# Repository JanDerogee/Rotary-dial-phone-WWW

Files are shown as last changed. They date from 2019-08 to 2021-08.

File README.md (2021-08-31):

# Rotary-dial-phone-WWW
Rotary dial phone WWW (for your Windows computer).

Allow your first 8 bookmarks to be opened with a number form a rotary dial phone.
Dial IP-address, using a rotary dial phone. Dial number based URL's (interesting if you like Chinese websites).
Do some basic calculations using a rotary dial phone.

Basically the phone is connected to an arduino circuit that converts the hook and dial functions into keystrokes. The magic is performed by cleverly executing sequences of standard keyboard shortcuts. Therefore no additional software needs to be installed.

For more information, visit the project page:
https://janderogee.com/projects/rotary_dial_phone_www/rotary_dial_phone_www.html

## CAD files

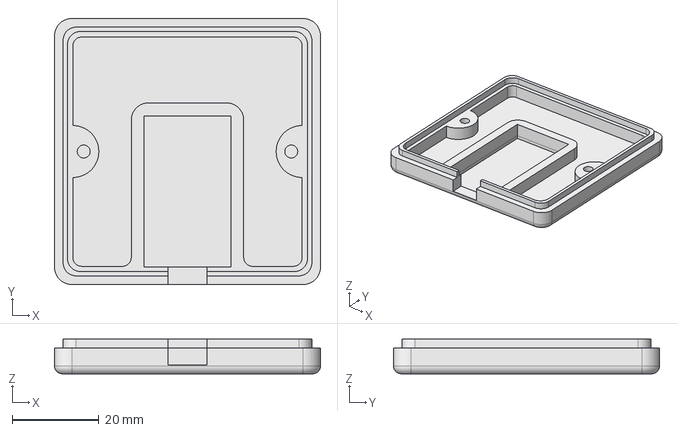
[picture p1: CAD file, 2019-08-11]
3D_printed_case_bottom/case_v1.0.FCStd
61.5 x 61.5 x 8.00 mm

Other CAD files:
3D_printed_case_bottom/case_v1.0.stl

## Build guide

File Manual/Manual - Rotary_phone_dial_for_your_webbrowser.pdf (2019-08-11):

# Rotary dial phone for your webbrowser

(for your MS Windows 7/8/10 computer in combination with Firefox)

this manual is intended for firmware version: V20190623 or higher

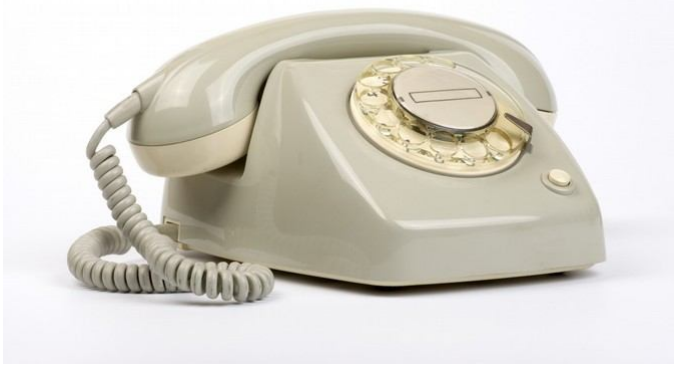
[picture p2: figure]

## By: Jan Derogee (2019)

## Introduction

Control your MS Windows 7/8/10 computer's webbrowser or calculator with an ordinary rotary dial phone. Surprise your friends or colleagues with this neat new application for obsolete tech.

Imagine this: You speak with a colleague about a specific website (that you have already bookmarked) and have a discussion about it that requires you both to take a look at it. So you offer to open a webbrowser to take a look, then you do not touch the keyboard or mouse, but reach for the rotary dial phone that was hidden underneath a pile of paperwork. You clear it out, pick up the dial, hear the dialtone and dial a number, bweeeeieieirieirieireip noises come from the receiver and the website shows up on your screen. You act like this is completely normal and continue the discussion about the contents of the site. Then when you are done, you hang up the phone and the webbrowser is closed and you continue like nothing special happened. Leaving your colleague in complete confusion about what he/she just witnessed. Now how fun is that?

You might wonder why somebody would make such a project. Well… just because for the fun of it and to maintain the skills of programming… okay… mostly for the fun of it.

2019-07-20 | Page 2 of 18 | Rotary dial phone WWW and Calc.

## Table of Contents

2019-07-20 | Page 3 of 18 | Rotary dial phone WWW and Calc.

## 1 History

### 1.1 What is a rotary phone

Rotary dial phones are the earliest user controlled phones to be mass produced. Prior to the rotary phone a user would pick up the phone, wait for the operator to answer and then tell the operator who they wanted to be connected with. With the rotary dial (pulse dialing), the user was able to make the connection themselves and therefore was no longer dependent on the speed/skill and presence of the previously used operator. This allowed the user to dial freely and at any time of day, allowing for quicker and more convenient connection to the people they wanted to speak with. This wonder of progress began to exist in 1919 and was to be slowly replaced by push buttons (tone dialing) since 1963.

### 1.2 How to use a rotary dial phone

The rotary dial phone isn't difficult to use, however it may be confusing for some people who never encountered this dialing system. Below is a wonderful set of images from WikiHow that shows you how to use this system.

First pick up the handpiece/receiver, and hold it against your ear, the cord is on the microphone side, which you should hold near your mouth while speaking. The if the first number of the telephone number you want to call is 5, place your finger in the hole with the number 5 and turn the disc, using your finger clockwise towards the fingerstop.

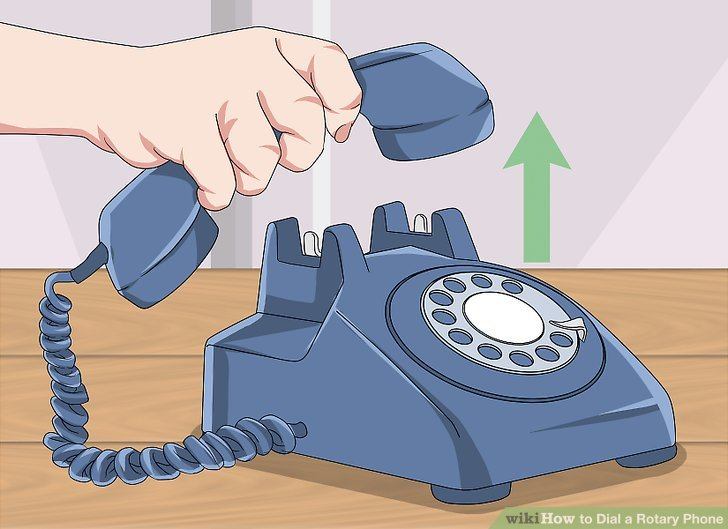
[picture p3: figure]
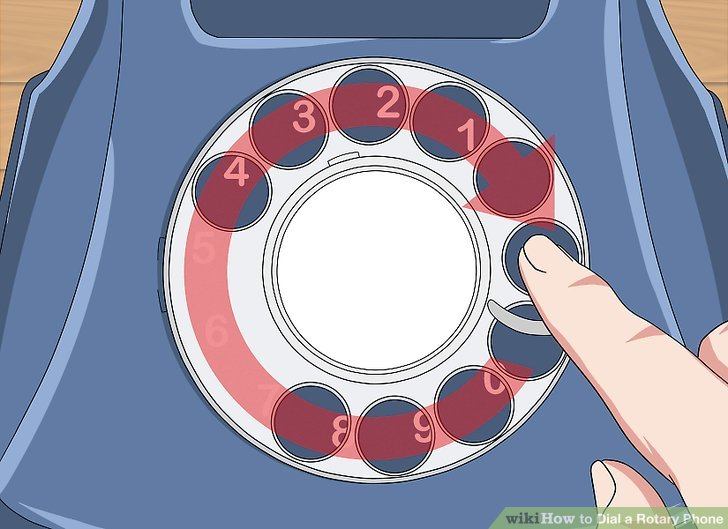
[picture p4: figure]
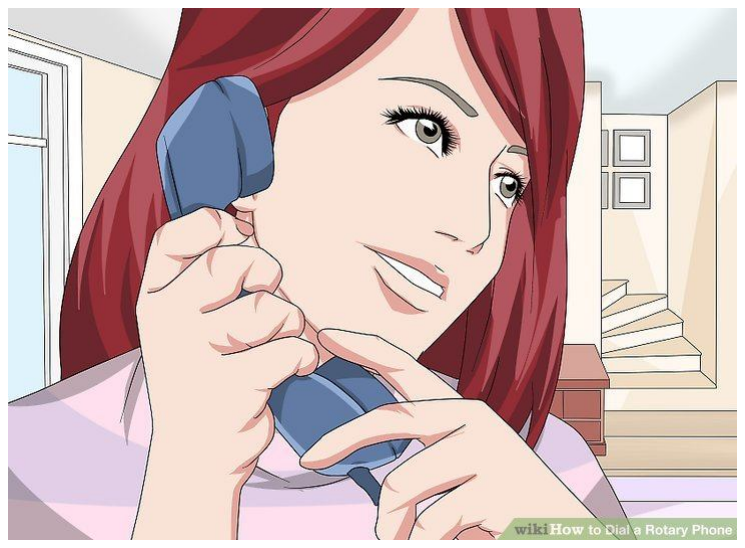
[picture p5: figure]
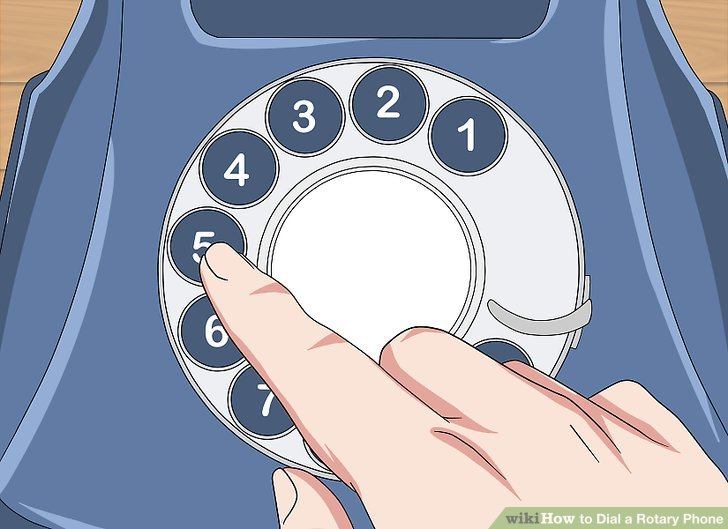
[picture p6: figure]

When your finger hits the fingerstop, pullback your finger from the disc, which will now turn back to it's original position making a soft clicking sound. When the disc stops turning dial the other numbers in the same way. When all numbers are dialed the connection is made and you may styart your conversation. Hang up the handpiece/receiver on the “hook” when your are finished.

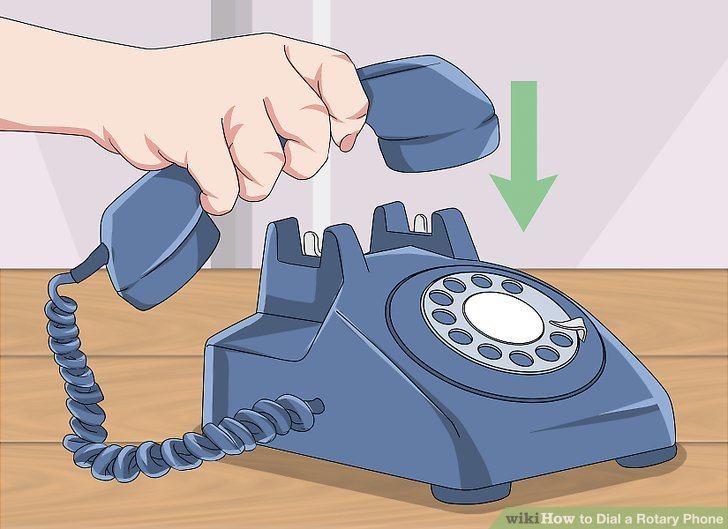
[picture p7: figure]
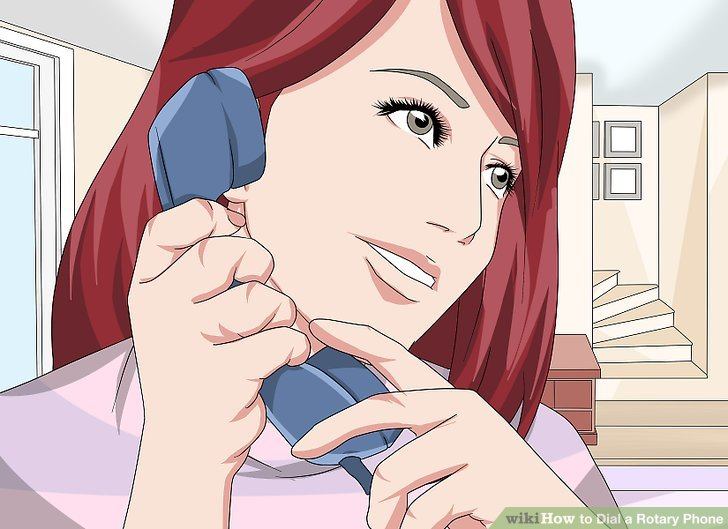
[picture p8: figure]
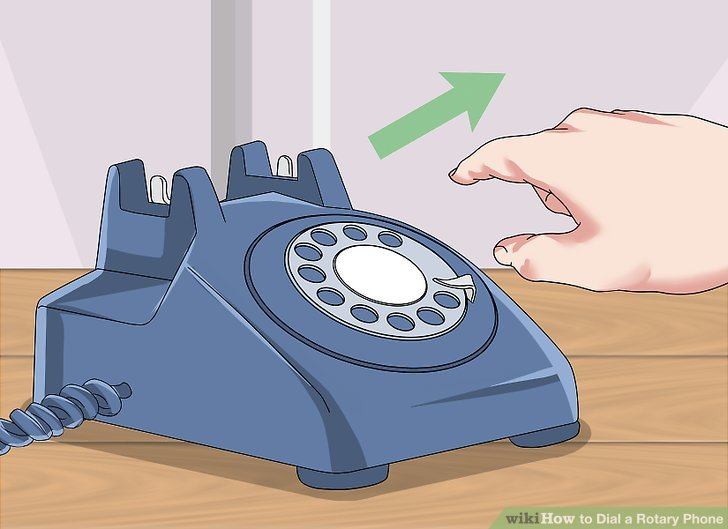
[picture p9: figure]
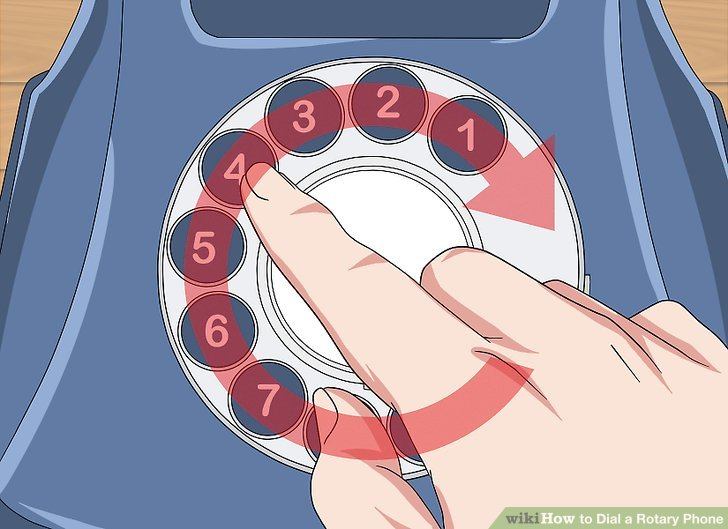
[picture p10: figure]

2019-07-20 | Page 4 of 18 | Rotary dial phone WWW and Calc.

## 2 System setup

No software needs to be installed, no special drivers are required. This device acts like a regular USB keyboard and is designed to operate with the Firefox webbrowser and the standard calculator app. But you do need to do some very simple “configurations” to your systems taskbar in order for this device to work properly:

In order to use the Firefox webbrowser it's icon should be placed onto the windows taskbar as the first item from the left. This allows it to be started using Windows+1 keyboard shortcut. You can achieve this by right clicking on the icon and selecting the option “add to taskbar” from the menu.

In order to use the calculator app it should be placed onto the windows taskbar as the second item from the left. This allows it to be started using the Windows+2 keyboard shortcut. You can achieve this by right clicking on the icon and selecting the option “add to taskbar” from the menu.

Below is an image that shows you how your taskbar could look like when this is done

## 3 Modes of operation

Now what this rotary phone to USB device does is using the phone not as a phone but as a device to control your webbrowser or calculator, by generating the keyboard codes that correspond to the functions coupled to the dial positions of the phones rotary dial.

There are 3 modes of operation, these modes of operation are described in the section “how to use” of this manual.

speeddial mode

open a webbrowser and use max. 8 different bookmarks from the bookmark menu

calculator mode

do some basic calculations usin the calculator application

IP-address and number based URL dialing mode

Dial an IP address for instance 123.1.2.3 or dial a number based URL like 126.com

2019-07-20 | Page 5 of 18 | Rotary dial phone WWW and Calc.

## 4 How to use it

The phone has a hook, a dial and a white button on the front panel. When taking the hook of the phone you can directly speed-dial a bookmark, or start the calculator app or start a browser and dial the IP address or number based URL. Pickup the handpiece/receiver, you will hear a dialtone, dial
0..9 to use a specific function: | 1..8 | = speeddial mode
| 9 | = calculator mode
| 0 | = IP / URL dial mode

The button is intended to put the dial into shifted mode.

### 4.1 Dial functions overview

The dial normally allows the user to enter a number from 0..9. However this is not enough for dialing IP-adresses or URL's. So in order to allow the user to enter different things than number alone, the small white button on the bottom-right corner of the phone is to be used to select different dial functions.

Pressing this button once activates the “shift”
function. Then dial the desired “shifted” function on
the dial. There is no way to un-shift, so if you didn't
really want a shift function and pressed the button by accident, just dial something and then delete it (by pressing the with button once followed by dialing a 1). Below an overview of the functions of the dial in normal and shifted mode.
NORMAL | SHIFTED
2019-07-20 | Page 6 of 18 | Rotary dial phone WWW and Calc.

Note: some people may ask “Why not use the character functions on the phone?”

That is a completely sensible question, because some phones have next to the numbers alphabetical characters. These characters were intended to make it easier for people to remember a phone number. As the numbers could be substituted by letters. For example: the number 0800-347396757 might be to difficult, especially when mentioned in a 10 second commercial. Therefore the number 0800-FIREWORKS would be much easier.

However, if these characters next to the
dial would be used to represent
characters from a URL, it would be
slightly | different, | as | the | device
(converting the pulses into numbers) no needs to now exactly what the user meant. When the user dialed a 5, he/she could have meant 5, J, K or L. Which is rather difficult to determine. So perhaps a scheme could be setup to dial a 5 one time for a 5, dial it 2 times for a J, 3 times for an K and 4 times for a L. Not impossible but it becomes confusing when the user want s to dial a 5 followed by a J, then you have 3 times a 5, which may be accepted as the input for a K, which is wrong. So perhaps a longer pause could be required between the numbers, but that would instantly conflict with user who want to dial quickly OR with user who dial too
slowly. Anyway, you can see where this
is going. And honestly, how many times

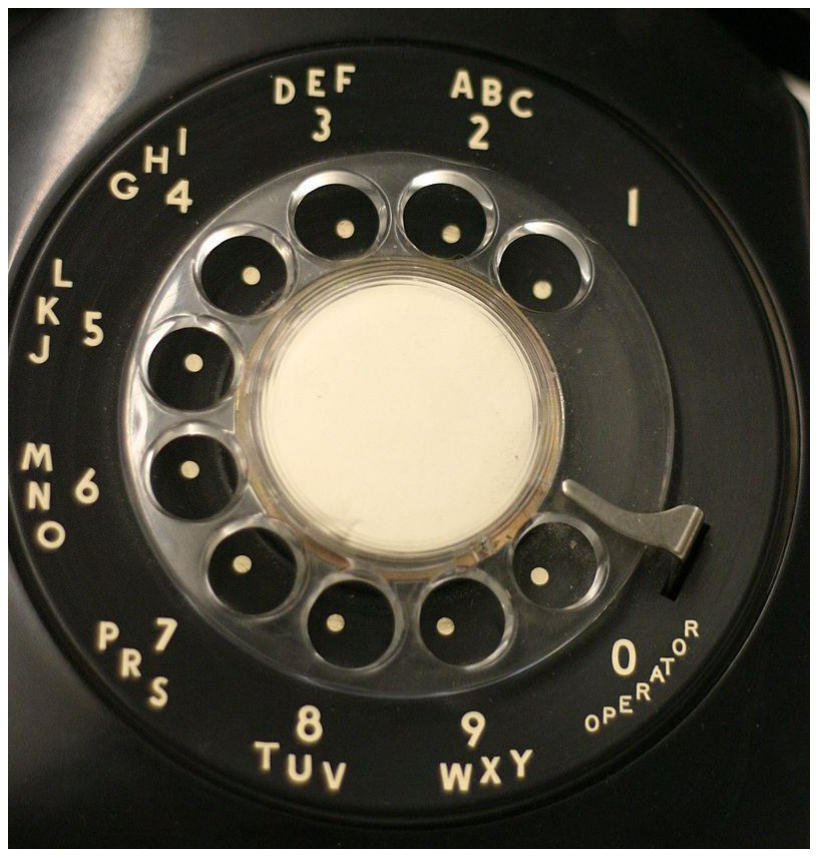
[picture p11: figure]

would you be using it, as it complicates things even further. Also the characters shown are not the complete alphabet and do not have special symbols like the '.' or the '/'. Certainly, technically everything is possible, but there is a limit to what is practically acceptable.

This project is intended as a gadget, a gag, a joke but certainly not as a full featured or serious input device. Simply because dialing y itself is rather slow and not the preferred method of choice for transferring text strings. The function of the speed dialing is perhaps the only function that makes this device slightly useable, but that's about it. Therefore during the development of this device no efforts were made to accommodate the input of raw alphabetical characters.

2019-07-20 | Page 7 of 18 | Rotary dial phone WWW and Calc.

### 4.2 Speeddial mode

The speeddial mode, will open a webbrowser and goes to the x-th item on your list of bookmarks. So assume you have a list of 25 bookmarks, then you can only access the top 8 using the speeddial function.

Pick up the handpiece/receiver, dial a number 1..8, this opens a webbrowser followed by opening the list of bookmarks. Then the cursor goes down to the selected item (1..8) and opens it.

When you are finished with the webbrowser, you must place the handpiece/reciever back onto the “hook” of the phone and the webbrowser will be closed.

In order for this to work you must setup your list of bookmarks correctly. Press CTRL+SHIFT+B to bring up the bookmarks window. The screenshot below shows how it may look like. By default it brings you to the “other bookmarks” folder and from that list it will select one of the top 8 (speeddial 1..8). If for any reason Firefox brings you to a different folder, then THAT will be the folder you must use. Although that may seems unlikely now, the other bookmarks folder wasn't default some time ago, so there is no knowing what future updates may bring us.

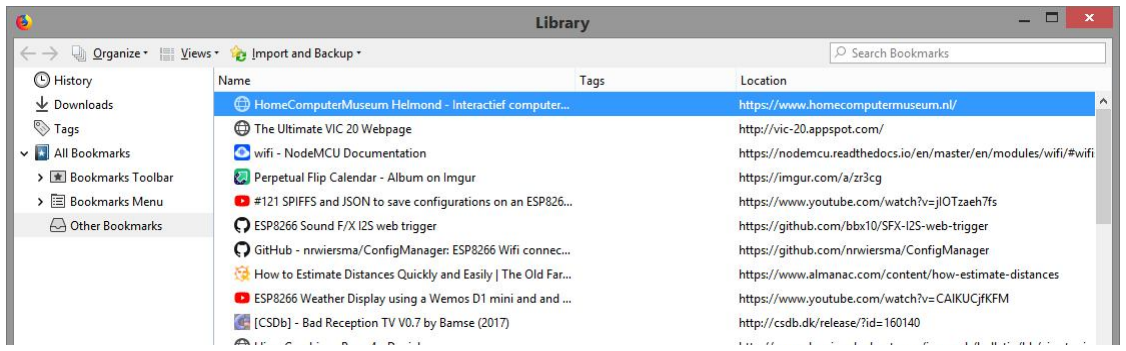
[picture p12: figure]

The top line (highlighted with blue) is the bookmark that will be started when speeddial 1 is used, the second line is the one started when speeddial 2 is used, etc. Just drag and drop the bookmarks you want to be under the speeddial in the first 8 locations of this list and that's all you need to do.

2019-07-20 | Page 8 of 18 | Rotary dial phone WWW and Calc.

### 4.3 Calculator mode

The calculator mode allows you to do some simple calculations, like adding, subtracting, multiplying and division.

Pick up the handpiece/receiver, dial a 9 to enter the calculator mode. And the calculator app will be openened. Now you can do some basic calculations by dialing the numbers 0..9 and functions . - + * / =

When you are finished with the calculator, you must place the handpiece/reciever back onto the “hook” of the phone and the calculator app will be closed.

2019-07-20 | Page 9 of 18 | Rotary dial phone WWW and Calc.

### 4.4 IP-address and number based URL dialing mode

This mode allows you to dial an IP address (i.e. 123.1.2.3) or a number based URL (i.e. 126.com).

### 4.4.1 Dial IP addresses

Pick up the handpiece/receiver, dial a 0 (just like you would dial a 0 on a company phone to connect to an outside line) and a browser will be opened.

Now you can dial the numbers of the IP address and for the '.' the 'enter' or the “.com” or any other kind of non numerical character you must use press the shift button then dial the desired character.

Unfortunately, not many websites allow you to directly visit them with an IP-address. Sometimes a warning is shown, something nothing happens at all. That's why the dialing of number based URLs is much more practical/fun.

### 4.4.2 Dial number based URL's

The Chinese, for various reasons, do use number based URL's. From a western perspective (considering I, the author of this manual, am from Europe) this sound a bit strange at first but there is a perfectly fine explanation for it, in the next chapter is explained why. But first this is how it works in practice:

Pick up handpiece/receiver, dial a 0 (just like you would dial a 0 on a company phone to connect to an outside line) and a browser will be opened.

Now you can dial the numbers of the IP address and for the '.' the 'enter' or the “.com” or any other kind of non numerical character you must use press the shift button then dial the desired character.

2019-07-20 | Page 10 of 18 | Rotary dial phone WWW and Calc.

## 5 Number based URL's and Chinese websites

Number based URL's aren't entirely non-existing but they are an exception in the western world. A few examples of the well known ones for some:

In the Netherlands, the URL 9292.nl originates from 0900-9292 (a phone number you can call to get public transport travel directions.

In Sweden there's 1177.se a website for health care

In the UK there's 111.nhs.uk an online (non urgent) emergency service. But also 118118.com which is a directory service provider that picked up a lot of popularity before mobile phones became the primary way to search for local businesses. They are still around though, and operate a website that is like a simplistic Yellow Pages / Yelp.

In Australia there's 131500.com.au the URL originates from the public transportation directions phone number of the past.

In Italy there's 187.it for Telecom Italia. Telephone companies customer service had (and still have) short numbers beginning with 1.

But the above number based URL's are merely to be considered as exceptions, we may state that most western websites have a text based URL. And having an URL or website that consists of a number may therefore be associated (by westerners) as cheap or may let them think that it really means that the most desirable version of a specific URL was already taken.

In China, though, that’s usually not the case. In fact it is the complete opposite to what most western people are accustomed to. Because if you are seriously looking at Chinese companies online, you may notice that it’s quite common for Chinese website names to include digits or even consist of numbers entirely. This is much less common with the names of English-language websites. There are a couple of reasons for this. Firstly, numbers are often easier for Chinese people to remember than Latin letters as these are not their native used symbols. Secondly, numbers often have extra meanings in Chinese. So you may now consider the fact that dialing a URL mainly consisting of numbers, using an old rotary dial phone like this project does, now becomes much less “strange” or ackward. You may even tend to believe that it could be practical to visit website using a rotary dial phone, but that would merely be a matter of personal taste.

### 5.1 Number based URL's are easy to remember

The numerals 0123456789 are used in China much as they are elsewhere in the world, and people learn them from a young age. This means they are very familiar to Chinese people and not seen as something foreign. But Latin letters, on the other hand, are generally much less familiar to many Chinese people. This may be less true for younger generations who study the Latin alphabet (thanks to Pinyin) from an early age, but in general Chinese people have less reason to use Latin letters day-to-day than they do with Arabic numerals.

The upshot of this is that Chinese website domains consisting of numbers can be much easier for Chinese people to remember than domains consisting of only Latin letters. This is often true even for domain names in pinyin – many Chinese people are not familiar with pinyin.

2019-07-20 | Page 11 of 18 | Rotary dial phone WWW and Calc.

### 5.2 Numbers have meanings in Chinese

The second reason number domain names are popular in China has to do with the huge number of homophones in the Chinese language. That is, the large amount of words that sound alike. Because there’s quite a limited amount of syllables in Chinese languages, many words end up sounding similar or identical. Numbers are no exception.

Because all numbers in Chinese sound similar to other words, it’s difficult to avoid certain associations growing between numbers and the words they sound like. This can also be put to use by intentionally choosing numbers to mimic the sounds of other words.

Here are some common associations between numbers and similar-sounding words in Chinese:
1 (一) can sound similar to ‘want’ or ‘is going to’ (要).

2 (二) can sound similar to ‘love’ (爱), but also means ‘stupid’!

3 (三) can sound similar to ‘life’ or ‘birth’ (生).

4 (四) is generally bad as it sounds like ‘death’ (死).

5 (五) is quite versatile, as it can sound similar to many different words. Most commonly it is used as ‘I / me’ (我 and 吾), and ‘not have’ (无).

6 (六) can sound like ‘flow / stream’ (流), ‘stay’ (留) and ‘fortune’ (禄).

7 (七) can sound like ‘arise’ (起).

8 (八) can sound like ‘prosper’ (发 in 发财), and two eights side-by-side (88) can look like the character for ‘double happiness’ (囍).

9 (九) can sound like ‘long lasting’ or ‘eternal’ (久).

Because of this, certain combinations of numbers can be quite significant. 14, for example, can sound like ‘will die’, and is thus quite undesirable. Similarly, 18 can sound like ‘will prosper’ and is quite desirable.

Digits are even more convenient when you consider that the words for numbers are homophones for other words. The URL for the massive e-commerce site Alibaba, for example, is 1688.com, which sounds when pronounced something like “yow-leeyoh-ba-ba”, not perfect perhaps, but very understandable and a good reminder.

But is isn't always about the way it sounds and the digits in a domain name usually aren’t random either. For example the Internet company NetEase uses the web address 163.com. This is a throwback to the days of dial-up internet when Chinese Internet users had to enter 163 to get online. And the phone companies China Telecom and China Unicom simply reappropriated their well-known customer service numbers as domain names, 10086.cn and 10010.cn, respectively.

And finally, there’s the wide, wild world of Chinese internet slang which may have originated by the fact of people dodging censors (or just nosy parents) and using homophonic numerals are perfect for such a task. So 748 is telling someone to go to hell, 555 basically means a crying emoji, 233 means you’re laughing, and 520 is ‘I love you’. And if you wanted to really kick it up a few notches, there’s 2010000, which means ‘I love you for 10,000 years’. How’s that for your Valentine’s Day Instagram hashtag?

2019-07-20 | Page 12 of 18 | Rotary dial phone WWW and Calc.

### 5.3 Examples of Chinese Website Names with Numbers

The effects described above would have been used when the below Chinese website names were created:

126.com and 163.com are owned by Netease, which is a general Internet services website, similar to Yahoo. Many people in China use 126.com for their email. 126 read in Chinese sounds very roughly like “I love you” in English.

88.com | online gaming and general Internet services website.
51.com | online gaming site. The name sounds like “I want”.
51job.com | job search website. The name sounds like “I want a job”.
56.com | video-streaming website. The name sounds like “I stream”.
3.cn | a shortcut to Jingdong Mall (is at jd.com)
4399.com | China’s first and largest online gaming website
92.com | buying and selling used cars
12306.cn | a place to order your train tickets
4008-517-517.com | McDonalds’ delivery online, “517” sounds a bit like “I want to eat.”

Note that official Chinese company names are always written in Chinese characters even though these aren't always included on their website. It's important to realize that the English names of Chinese companies aren't the true companies name, but just a way to name them in the west.

### 5.4 Why don’t the Chinese use Mandarin based URL's

You may ask yourself, “why don’t Chinese web addresses just use Mandarin characters?” well that's because that’s a pain, too. The Internet Corporation for Assigned Names and Numbers (ICANN), which sets the rules for web addresses globally, has periodically hyped the expansion of domain names to include non-Latinate scripts, but Chinese web sites have yet to take full advantage.

Keep also in mind that it is difficult to type Chinese characters on an alphabet-based keyboard.

Some devices require a special plug-in to type in Chinese URLs, and even then it takes longer to type or write out characters than to input a few digits. Plus, for web sites that want to expand internationally but don’t want to alienate foreign audiences with unfamiliar characters, numbers are a decent compromise.

2019-07-20 | Page 13 of 18 | Rotary dial phone WWW and Calc.

## 6 Trouble shooting

In some cases when you try to use the phone, it doesn't work as expected. Things may happen and things may fail. The way the system works, is by generating keyboard codes, so it works just a like a user pressing buttons on his/her keyboard. Sometimes it takes a while for an application to start, firefox may tike quite a few seconds to start when your computer has just been switched on, this is quite normal. But because it takes so long to start, the keyboard codes that have been send, are missed by the Firefox web-browser, since it wasn't ready for it yet.

Just close firefox and you'll notice that the seconds time you'll open it, it will be much quicker to start, the system allows for a startup time of max. 1.5seconds and then starts sending the keyboard codes.

Now there is now way for the device to know when the application that is opened is fully started, it effectively is typing blind on the keyboard and hopes for the best. There are 2 methods that can be used to implement it's operation. 1: the device opens the application and waits for 10 seconds or a minute or whatever, but it does so every time you use it and then send the keyboard codes, meaning that it responds all very very slow but always works. 2:the device opens the application and waits for 1.5 second then starts sending the keyboard codes. Now this may fail the first time it is used, but after that it works and it works quite quickly. Therefore, for practical reasons, you now understand why method 2 is implemented in this device as it is no big deal if it fails the first time (unless you've opened a Firefox webbrowser manually just before) but it becomes annoying quite quickly if it responds painstakingly slow...

2019-07-20 | Page 14 of 18 | Rotary dial phone WWW and Calc.

## 7 Easter eggs

Easter eggs are little jokes put into a device by the programmer during development of the product. Sometimes an easter egg is a way of putting a name tag into the code, allowing the programmer to claim the software to be his/hers in a later stage. Sometimes an easter egg allows for additional functionality in the form of a small game. Sometimes an easter egg is just an homage to something historical or sentimental. But in all cases an easter egg is supposed to be a harmless little joke created by using the otherwise unused space in a programs memory.

Normally, easter eggs are to be hidden and not shown in a manual, perhaps a small hint but never directly as printed here. The reason why it is printed here is simple… nobody would notice this functionality otherwise. And what is the fun in a joke if notices it?

And this device has an easter egg too. Just 3 small functions that are a reminder to the past. When you dial one of the numbers below you will be send directly to a website related to that number. The numbers are typically Dutch service numbers from the 1980's for time, weather and information. The fun in these is that you can dial them just like back then and get a similar result.

This is how you can trigger the easter eggs, there not really that complicated, it's just like dialing the phone number as you would on a company phone where you would need to dial a 0 to get to the outside line then the 3-digit number to get the desired service.

Pick up phone, dial 0 (this starts the browser), then dial 002 (002 was the number you would dial to get the current time) a website is opened that provides you with similar information.

Pick up phone, dial 0 (this starts the browser), then dial 003 (003 was the number you would dial to get a national weather forecast) a website is opened that provides you with similar information.

Pick up phone, dial 0 (this starts the browser), then dial 008 (008 was the number you would dial to get information about a specific telephone number) a website is opened that provides you with similar information.

Pick up phone, dial 0 (this starts the browser), then dial 3.14159 (and go to the wikipedia page of the magical number on which our whole society is build).

Pick up phone, dial 0 (this starts the browser), then dial 1.1.2.3.5.8.13.21 (and go to the wikipedia page of the Fibonacci_number)

2019-07-20 | Page 15 of 18 | Rotary dial phone WWW and Calc.

## 8 Schematic

The schematic of this project is nothing more then an Arduino Pro Micro and 2 resistors, all connected to the phone using 3 wires. Below how to connect it all.

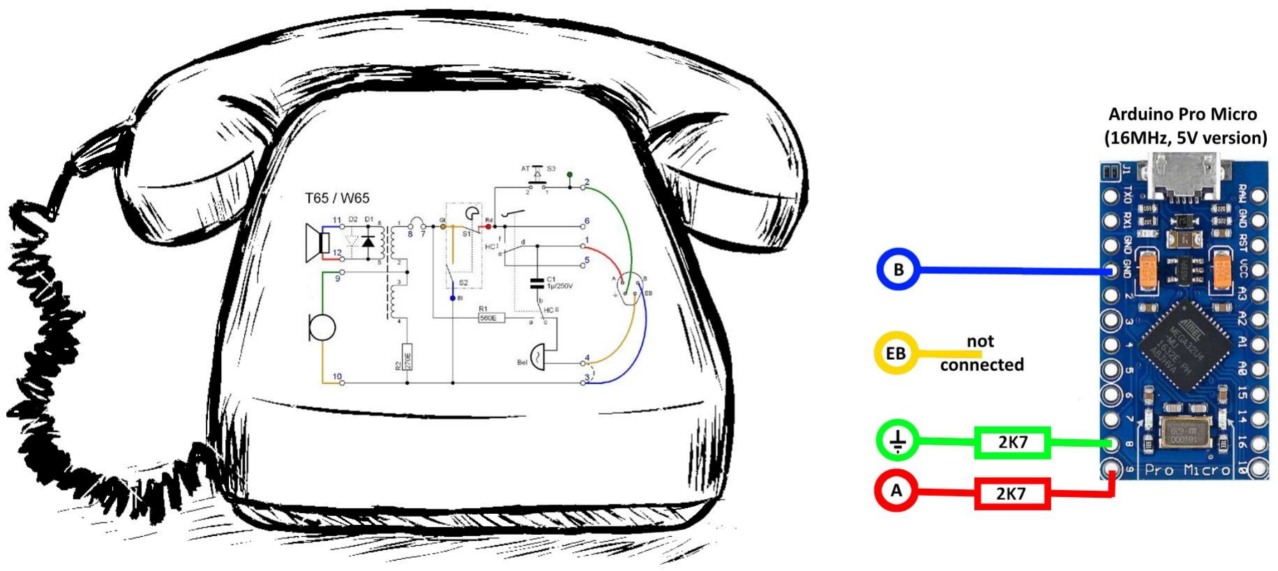
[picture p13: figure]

2019-07-20 | Page 16 of 18 | Rotary dial phone WWW and Calc.

## 9 How it works

The whole project is nothing more then a spiced up keyboard example for the Arduino Pro Micro (or Arduino Leonardo). So despite the tech of an Atmega 32u4 behaving like a keyboard… no other special magic happens.

The main reason to do it like this is simply because it is the easiest as no special drivers are required. Everything works out of the box. This way you can use it on any computer even if you don't have administrator rights for it and therefore aren't allowed to install any kind of software or drivers. Which might be the case if you want to use this device at work.

In order to control your computer through the use of only a keyboard there is a small trick to be pulled, it is the trick of using keyboard shortcuts. Keyboard shortcuts are quite normal keyboard commands for general purposes (OS related shortcuts) or for a specific type of program (program related shortcuts).

Because this device acts like a keyboard, the information is going only in one direction. From keyboard to computer. There is no way the computer can let the keyboard know in which state it's in. This means that you cannot just send a set of keypresses and hope for the best, because then weird things will happen eventually. So the trick here is to force the OS (using OS related shortcuts) into a known state and work your way up to the program from there and then perform the program related shortcuts.

Opening the webbrowser (which is an app expected to be located on the first position of the taskbar) can be started using :

WINDOWSKEY+1 = start 1st item on the taskbar

but this would be problematic when Firefox is already open, as it would mean that we don't know in which state it is and this causes problem especially when closing it later on, because we might be closing something the user doens't want to be closed. So it would be best to open up a completely independent instance of the webbrowser:

KEY_LEFT_GUI + KEY_LEFT_SHIFT + 1

Focus to the taskbar and open a new instance of the app on the first position of the taskbar

delay for 2.5 seconds | Allow some time for the app to start
KEY_CONTROL+L | Focus the address bar (and selects all within) so you can begin typing
KEY_DELETE | Clear text if there was any

Opening the bookmarks menu and selecting an item could be the following set of key events:

KEY_LEFT_ALT, B, KEY_DOWN_ARROW, KEY_DOWN_ARROW, KEY_RETURN

But unfortunately… this seems to work on an English version of the OS and therefore an English version of Firefox will be installed. But doesn't work when a Dutch OS is running and a Dutch version of Firefox is installed. Because in the Dutch version the B isn't used for Bookmarks but for something completely different. Instead an A (for blAdwijzer) would be required. This makes this

2019-07-20 | Page 17 of 18 | Rotary dial phone WWW and Calc.

sequence of keypresses almost completely useless if you want to use it on different systems. Therefore a different combination must be used. Fortunately, the use of the combination:

KEY_CONTROL+SHIFT+B, KEY_DOWN_ARROW, KEY_DOWN_ARROW, KEY_RETURN

does something similar and equally useful. Therefore this combination will be the preferred one for this project.

Finally, when the user decides to hangup the receiver on the hook (terminate the call), the webbrowser must be closed. Closing the webbrowser is something similar:

KEY_LEFT_GUI + T | Focus to or "open" the taskbar
KEY_HOME | Make sure we are at the start (first position)
KEY_UP_ARROW | Arrow up to make a selection from currently opened instances
KEY_END | Choose the last instance of the application (this fails only if the user
has openend another instance manually after using the phone BEFORE the receiver was put down
KEY_RETURN | Confirm chosen selection from the (possible) list of items

KEY_LEFT_ALT+KEY_F4 The application close command

So as you can see, it is not impossible to control your computer through the use of blind keyboard presses. But you have to make sure you are using the right key events, otherwise you might be doing things that may be something completely “undesirable” if you are executing these in the wrong application. Therefore as shown above, care has to be taken to prevent this as much as possible. By forcing an extra HOME command and using new instances.

2019-07-20 | Page 18 of 18 | Rotary dial phone WWW and Calc.

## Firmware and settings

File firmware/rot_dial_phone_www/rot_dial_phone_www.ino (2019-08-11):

/*
  CBM/Atari Paddle to volume control converter

  For Leonardo, Pro Micro and Due boards only.

  Convert the classic rotary dial phone to an webbrowser controller
  Allowing the user to dial an IP address

  This project does require some small tricks to be pulled mostly based on keyboard shortcuts available in the browser and Windows OS
  for more info about the keyboard key names: https://www.arduino.cc/en/Reference/KeyboardModifiers
  for more info about keyboard shortcuts in webbrowsers: https://www.howtogeek.com/114518/47-keyboard-shortcuts-that-work-in-all-web-browsers/

*/

#include "Keyboard.h"
#include "phone_enums.h"

/*IO-defintions*/
#define mode_select   15 /*switch used to select the mode (allow easy disabling of sometimes anoying mouse, usefull for debugging*/
#define ph_button     8  /*the white button on the front of the phone*/
#define ph_hookpulse  9  /*the hook of the rotary dial phone*/


/*defines*/
#define DELAY_LONG     250   /*response delay, in ms*/
#define PULSE_TIMEOUTVAL 25 /*.. times 10msec*/

/*-----------------------------------------------------------------------*/

/*routines*/
unsigned char PollPhone(void);
unsigned char CountDialPulses(void);
void OpenWebbrowser(void);
void CloseWebbrowser(void);
void OpenCalculator(void);
void CloseCalculator(void);
void SpeedDial(unsigned char mem);
void Sound_DialUpModem(void);
void Sound_Tone(unsigned int period, unsigned int duration);
void EasterEgg(String str);
void Backspace(unsigned char lp);

/*globals*/
//unsigned char lp = 0;
boolean WebbrowserOpen = false;     /*this flag is used to keep track of the status of the webbrowser, if it isn't open, it should not be closed (otherwise we might be closing the wrong app*/
boolean CalculatorOpen = false;     /*this flag is used to keep track of the status of the calculator, if it isn't open, it should not be closed (otherwise we might be closing the wrong app*/

/*-----------------------------------------------------------------------*/

void setup()
{
  pinMode(mode_select, INPUT_PULLUP);   /*initialize IO*/
  pinMode(ph_button, INPUT_PULLUP);
  pinMode(ph_hookpulse, INPUT_PULLUP);

  Serial.begin(115200);     /*open a serial connection, for debugging purposes only*/
  
  //while (!Serial) ;         /*to make sure we miss nothing printed to the virtual COM-port, keep looping until the serial stream is opened*/
  /*But beware, this means the application WILL stay here until a COM is opened, meaning that an application (arduino IDE or terminal) must be running!!!*/
  
  Serial.println("Hello this is debugging information");
  Serial.println("Rotary dial IP dialing");

  Keyboard.begin();
}

/*-----------------------------------------------------------------------*/

void loop()
{
  unsigned char value;
  static String dial_string = "";
  while (digitalRead(mode_select) == 0) /*for debugging purposes, it is very usefull to disable the projects functionaly... considering it is always connected and may not always behave as expected/desired during development*/
  {
    delay(1000); /*do nothing*/
    Serial.println("Project disabled...");
  }

  value = PollPhone();
  switch(value)
  {
    case PHONE_OFF_HOOK:
    {
      dial_string = ""; /*reset the dial string*/
      break;
    }

    case PHONE_SPEEDDIAL_HANG_UP:
    case PHONE_URL_HANG_UP:    
    {
      CloseWebbrowser();
      break;
    }    

    case PHONE_CALCULATOR_HANG_UP:
    {
      CloseCalculator();
      break;
    }    

    case PHONE_SPEEDDIAL_1:
    case PHONE_SPEEDDIAL_2:
    case PHONE_SPEEDDIAL_3:
    case PHONE_SPEEDDIAL_4:
    case PHONE_SPEEDDIAL_5:
    case PHONE_SPEEDDIAL_6:
    case PHONE_SPEEDDIAL_7:
    case PHONE_SPEEDDIAL_8:    
    {
      OpenWebbrowser();            
      value = value - PHONE_SPEEDDIAL_1 + 1; /*remove the offset from the enum to get a value from 1-8, that will be parsed to the SpeedDial routine that opens the ..th bookmark fromthe bookmark list*/
      SpeedDial(value); 
      Sound_DialUpModem();              
      break;                  
    }

    case PHONE_URL:
    {
      OpenWebbrowser();      
      break;
    }

    case PHONE_URL_0:
    case PHONE_URL_1:
    case PHONE_URL_2:
    case PHONE_URL_3:
    case PHONE_URL_4:
    case PHONE_URL_5:
    case PHONE_URL_6:
    case PHONE_URL_7:
    case PHONE_URL_8:
    case PHONE_URL_9:
    {
      value = value - PHONE_URL_0;        /*remove the offset from the enum to get the value from 0-9*/
      Keyboard.print(value);              /*the print function converts the value (of the conveniently chosen enum) to the ASCII character(s) representing of that value*/
      dial_string = dial_string + value;
      EasterEgg(dial_string);             /*check if the currently dialed number equals an easter egg and handle accordingly*/
      break;                  
    }

    case PHONE_CALCULATOR:
    {
      OpenCalculator();       
      break;
    }
       
    case PHONE_CALC_0:
    case PHONE_CALC_1:
    case PHONE_CALC_2:
    case PHONE_CALC_3:
    case PHONE_CALC_4:    
    case PHONE_CALC_5:
    case PHONE_CALC_6:
    case PHONE_CALC_7:
    case PHONE_CALC_8:
    case PHONE_CALC_9:
    {
      value = value - PHONE_CALC_0;       /*remove the offset from the enum to get the value from 0-9*/
      Keyboard.print(value);              /*the print function converts the value (of the conveniently chosen enum) to the ASCII character(s) representing of that value*/
      dial_string = dial_string + value;
      break;                  
    }

    case PHONE_CALC_DELETE:
    case PHONE_URL_DELETE:
    {
      Backspace(1);                                 /*do a single backspace*/
      dial_string.remove(dial_string.length()-1);   // Remove last char
      break;                  
    }

    case PHONE_CALC_DOT:
    case PHONE_URL_DOT:
    {
      Keyboard.press('.');
      Keyboard.releaseAll();
      dial_string = dial_string + ".";
      break;
    }

    case PHONE_CALC_DOTCOM:
    {
      break;    
    }
    
    case PHONE_URL_DOTCOM:
    {
      Keyboard.print(".com");
      Keyboard.press(KEY_RETURN);
      Keyboard.releaseAll();
      dial_string = dial_string + ".com";
      Sound_DialUpModem();                    
      break;
    }

    case PHONE_CALC_DOTCN:
    {
      break;    
    }
    
    case PHONE_URL_DOTCN:
     {
      Keyboard.print(".cn");
      Keyboard.press(KEY_RETURN);
      Keyboard.releaseAll();
      dial_string = dial_string + ".cn";
      Sound_DialUpModem();                    
      break;
    }

    case PHONE_CALC_MINUS:
    case PHONE_URL_MINUS:
    {
      Keyboard.press('-');
      Keyboard.releaseAll();
      dial_string = dial_string + "-";
      break;
    }

    case PHONE_CALC_PLUS:
    case PHONE_URL_PLUS:
    {
      Keyboard.press('+');
      Keyboard.releaseAll();
      dial_string = dial_string + "+";
      break;
    }

    case PHONE_CALC_STAR:    
    case PHONE_URL_STAR:
    {
      Keyboard.press('*');
      Keyboard.releaseAll();
      dial_string = dial_string + "*";
      break;
    }

    case PHONE_CALC_SLASH:    
    case PHONE_URL_SLASH:
    {
      Keyboard.press('/');
      Keyboard.releaseAll();
      dial_string = dial_string + "/";
      break;
    }

    case PHONE_CALC_EQUAL:    
    case PHONE_URL_EQUAL:
    {
      Keyboard.press('=');
      Keyboard.releaseAll();
      dial_string = dial_string + "=";
      break;
    }

    case PHONE_CALC_RETURN:
    {
      Keyboard.press(KEY_RETURN);
      Keyboard.releaseAll();
      break;
    }    
    
    case PHONE_URL_RETURN:
    {
      Keyboard.press(KEY_RETURN);
      Keyboard.releaseAll();
      Sound_DialUpModem();        
      break;
    }    
   
    case PHONE_IDLE:  /*when the phone is on the hook*/
    default:
    {
      break;
    }
  }

}


/*-----------------------------------------------------------------*/


/*this routine will poll the phone for user input*/
/*it responds with an enumerated event value*/
unsigned char PollPhone(void)
{   
  static unsigned char phone_state = STATE_HOOK_DOWN;   /*the statemachine of the phones behaviour*/
  static unsigned char phone_mode = MODE_SPEEDDIAL;     /*the mode in which we are using the phone*/
  static unsigned char shift = false;                   /*the shift function allows double functions on the dial*/
  unsigned char dial_val = 255;
  unsigned int tone_delay = 0;
  unsigned char ret_val = PHONE_IDLE; 

  switch(phone_state)
  {   
    case STATE_HOOK_PICK_UP:
    { /*check for activity, hook or pulse, sound a dial tone to indicate the system is ready for input*/      
      pinMode(ph_hookpulse, INPUT_PULLUP);    /*set IO-pin to input (if not already) pickup is easily detected by watching if the pin goes low*/      
      while(digitalRead(ph_hookpulse) == 0)   /*a while loop is the only way to get a glitchfree dial-tone, PWM doesn't sound good enough as the input pin testing results in unwanted noise*/
      {                                       /*though the blocking character of the while loop is not a big issue during this state, because now we have full control over the produced wave and can do IO-readings when the pin is at a known state*/
        Sound_Tone(2500, 1);                  /*generate a single cyle of the desired tone*/
      }     
      phone_state = STATE_DIAL;
      ret_val = PHONE_IDLE;        
      break;
    }     

    case STATE_DIAL:
    {
      dial_val = CountDialPulses();
      if(dial_val == 255)
      {
        phone_state = STATE_HOOK_DOWN;    /*oops, the user aborted by hanging the handpiece up on the hook*/
        switch(phone_mode)
        {
          case MODE_SPEEDDIAL:  {ret_val = PHONE_SPEEDDIAL_HANG_UP; break;}
          case MODE_CALCULATOR: {ret_val = PHONE_CALCULATOR_HANG_UP; break;}
          case MODE_URL:        {ret_val = PHONE_URL_HANG_UP; break;}
          default:              {ret_val = PHONE_IDLE; break;}
        }
      }
      else
      {
        phone_state = STATE_WAIT_FOR_INPUT;
        switch(phone_mode)
        {
          case MODE_SPEEDDIAL:
          {            
            switch(dial_val)
            {
              case 9:   {ret_val = PHONE_CALCULATOR; phone_mode = MODE_CALCULATOR; break;}
              case 0:   {ret_val = PHONE_URL; phone_mode = MODE_URL; break;}              
              default:  {ret_val = PHONE_SPEEDDIAL_1 + (dial_val-1); break;}            
            }
            break;
          }

          case MODE_CALCULATOR:
          {
            if(shift == true) {ret_val = PHONE_CALC_RETURN + dial_val;} /*convert the value of pulse_count to a value represented by the enum definition*/                                            
            else              {ret_val = PHONE_CALC_0 + dial_val;}      /*convert the value of pulse_count to a value represented by the enum definition*/                              
            shift = false;  /*reset shift*/
            break;
          }

          case MODE_URL:
          {
            if(shift == true) {ret_val = PHONE_URL_RETURN + dial_val;}  /*convert the value of pulse_count to a value represented by the enum definition*/                                            
            else              {ret_val = PHONE_URL_0 + dial_val;}       /*convert the value of pulse_count to a value represented by the enum definition*/                              
            shift = false;  /*reset shift*/
            break;
          }

          default:
          {
            break;
          }
        }
      }      
      break;
    }

    case STATE_WAIT_FOR_INPUT:
    {
      if(digitalRead(ph_button) == 0)       /*check for button activity*/
      {
        while(digitalRead(ph_button) == 0)  /*keep looping until released, produce a tone while pressing the button*/
        {
            Sound_Tone(8000, 1);      /*confirm button press with audible tone*/
            shift = true;             /*the button was pressed, this means that shift is active*/
        }
        pinMode(ph_hookpulse, INPUT_PULLUP);    /*set IO-pin to input, this way the phone makes no sound and draws no unwanted DC-current*/      
        Serial.println("Button press detected");  
        phone_state = STATE_WAIT_FOR_INPUT;
        break;      
      }
      
      if(digitalRead(ph_hookpulse) == 1)    /*check for pulse activity*/
      {
        phone_state = STATE_DIAL;            /*go to the dial (pulse decoding) state*/
      }      
      ret_val = PHONE_IDLE;              
      break;
    }

    case STATE_HOOK_DOWN:
    default:
    {
      pinMode(ph_hookpulse, INPUT_PULLUP);  /*set IO-pin to input, this way the phone makes no sound and hook pickup is easily detected, by wathcing if the pin goes low*/
      if(digitalRead(ph_hookpulse) == 0)    /*check if hook is picked up*/
      {
        Serial.println("Hook is picked up");
        delay(DELAY_LONG);                    /*delay to wait out the noisy signals created by the hook switch*/
        phone_state = STATE_HOOK_PICK_UP;     /*new state is hook pick up*/
        phone_mode = MODE_SPEEDDIAL;          /*default mode is speed dial mode*/        
        shift = false;                        /*default shift is not pressed*/
        ret_val = PHONE_OFF_HOOK;             /*signal this event to the caller of this routine*/
      }
      else
      {
        ret_val = PHONE_IDLE;
      }
      break;
    }
  }  

  return(ret_val);
}

/*this routine decodes the signal on the hook/pulse line and counts pulses or detects hang-up (receiver put back onto the hook)*/
unsigned char CountDialPulses(void)
{
  bool cur_pulse_state = HIGH;
  bool prev_pulse_state = HIGH; 
  unsigned char pulse_count = 0;
  unsigned char pulse_timeout = 0;
  
  pulse_timeout = PULSE_TIMEOUTVAL; /*reset timeout counter*/
  while(pulse_timeout > 0)  /*if the signal is too high for too long, then this isn't a valid pulse (user hangup or user pressing hookswitch)*/
  {
    prev_pulse_state = cur_pulse_state;
    cur_pulse_state = digitalRead(ph_hookpulse);       
    if((cur_pulse_state == LOW) && (prev_pulse_state == HIGH))        
    {
      pulse_count++;          
      pulse_timeout = PULSE_TIMEOUTVAL; /*reset timeout counter*/          
    }
    else
    {
      delay(10);
      pulse_timeout--;          
    }
  }

  if(digitalRead(ph_hookpulse) == LOW)  /*check current state of hook/pulse signal to determine whether we are hung up or done dialing*/
  {
    Serial.print("detected pulses=");
    Serial.print(pulse_count);
    Serial.print(", this means the user dialed the value ");
    if(pulse_count > 9) {pulse_count = 0;};       /*when 10 pulses are counted this means the value 0 is dialed, se here we correct for that to get the correct numerical value*/
    Serial.println(pulse_count);
    return(pulse_count);
  }
  else
  {
    Serial.println("phone hung up");
    return(255);    /*255=error value for "hung up"*/
  }      
}
    
/*this routine sends keyboard shortcuts to open a webbrowser*/
/*make sure that your desired webbrowser is placed as the 1st item on your taskbar (so that it can be started with the key combo: WINDOWSKEY+SHIFT+1)*/
/*the code below could have been written in loop-style reading an array of actions to save space, but this was easier to code AND easier to read back (due to comments), which might be usefull for other when reading and modifying it*/
void OpenWebbrowser(void)
{    
    /*WINDOWSKEY+1 = start 1st item on the taskbar (which should be firefox or any other webbroswer)*/
    Keyboard.press(KEY_LEFT_GUI);
    Keyboard.press(KEY_LEFT_SHIFT); /*Open a new instance of the application located on the first position of the taskbar*/
    Keyboard.press('1');
    Keyboard.releaseAll();
    delay(2500);  /*allow some time for the app to start*/

    /*CONTROL+L = focus the address bar (and selects all within) so you can begin typing.*/
    Keyboard.press(KEY_LEFT_CTRL);
    Keyboard.press('l');
    Keyboard.releaseAll();
    delay(250);

    /*clear everything that is already present in the URL filed, if there is nothing thennothing will change, if there was something it will be gone*/
    Keyboard.press(KEY_DELETE);
    Keyboard.releaseAll();
    delay(250);   

    WebbrowserOpen = true;  /*raise flag, so that we know that the webbrowser is opened*/
}

/*the opposite to the openwebbrowser routine, this routine expects the webbrowser to be on top and have the focus*/
void CloseWebbrowser(void)
{ 
  if(WebbrowserOpen == true)   
  {
    WebbrowserOpen = false;
    Serial.println("Closing webbrowser");
    
    Keyboard.press(KEY_LEFT_GUI);     /*set focus to or "open" the taskbar*/
    Keyboard.press('t');    
    Keyboard.releaseAll();
    delay(250);   

    Keyboard.press(KEY_HOME);         /*make sure we are at the start*/
    Keyboard.releaseAll();
    delay(100);   

    Keyboard.press(KEY_UP_ARROW);     /*arrow up allows 'the user" to make a choice from the list of currently opened instances of this program*/
    Keyboard.releaseAll();
    delay(100);   
     
    Keyboard.press(KEY_END);          /*choose the last instance of the application*/
    Keyboard.releaseAll();
    delay(100);   
     
    Keyboard.press(KEY_RETURN);       /*confirm the currently chosen selection from the (possible) list of items)*/
    Keyboard.releaseAll();
    delay(100);   
    
    Keyboard.press(KEY_LEFT_ALT);     /*the close command*/
    Keyboard.press(KEY_F4);    
    Keyboard.releaseAll();
    delay(100);   
  }
  else
  {
    Serial.println("Webbrowser could not be closed because it wasn't opened");
  }
}

/*this routine sends keyboard shortcuts to open a calculator, make sure that the calculator is the 2nd item on the taskbar (so that it can be started with the key combo: WINDOWSKEY+SHIFT+2)*/
void OpenCalculator(void)
{
  Keyboard.press(KEY_LEFT_GUI);
  Keyboard.press(KEY_LEFT_SHIFT); /*Open a new instance of the application located on the second position of the taskbar*/
  Keyboard.press('2');
  Keyboard.releaseAll();
  delay(250);   
      
  CalculatorOpen = true;          /*raise flag, so that we know that the calculator is opened*/
}

/*the opposite to the opencalculator routine*/
void CloseCalculator(void)
{
  if(CalculatorOpen == true)   
  {
    CalculatorOpen = false;
    Serial.println("Closing calculator");
        
    Keyboard.press(KEY_LEFT_GUI);     /*set focus to or "open" the taskbar*/
    Keyboard.press('t');    
    Keyboard.releaseAll();
    delay(250);   

    Keyboard.press(KEY_HOME);         /*make sure we are at the start*/
    Keyboard.releaseAll();
    delay(100);   

    Keyboard.press(KEY_RIGHT_ARROW);     /*arrow right brings us to the second item on the taskbar*/
    Keyboard.releaseAll();
    delay(100);   

    Keyboard.press(KEY_UP_ARROW);     /*arrow up allows 'the user" ta make a choice from the list of currently opened instances of this program*/
    Keyboard.releaseAll();
    delay(100);   
     
    Keyboard.press(KEY_END);          /*choose the last instance of the application*/
    Keyboard.releaseAll();
    delay(100);   
     
    Keyboard.press(KEY_RETURN);       /*confirm the currently chosen selection from the (possible) list of items)*/
    Keyboard.releaseAll();

    Keyboard.press(KEY_LEFT_ALT);     /*the close command*/
    Keyboard.press(KEY_F4);    
    Keyboard.releaseAll();
    delay(100);
  } 
  else
  {
    Serial.println("Calculator could not be closed because it wasn't opened");
  }
}

/*this routine will browse through the bookmarks of firefox and selects one of the top 10 bookmarks*/
/*this way the speeddial is easily configured without the need for hardcoding anything into the firmware*/
void SpeedDial(unsigned char mem)
{
  unsigned char lp;

  /*open the bookmarks menu (this works for English OS only, because in English OS is the B (Bookmarks), but in Dutch OS, the A is used (blAdwijzers)*/
//  Keyboard.press(KEY_LEFT_ALT);
//  Keyboard.releaseAll();
//  delay(250);    
//  Keyboard.press('b');
//  Keyboard.releaseAll();
//  delay(100);    

  Keyboard.press(KEY_LEFT_CTRL);
  Keyboard.press(KEY_LEFT_SHIFT);
  Keyboard.press('b');
  Keyboard.releaseAll();
  delay(100);    


  if(mem==0)  
  {
    mem=10; /*the value 0 represents the 10th item on the list of items in the bookmarks menu*/
  }

  mem = mem-1;  /*the desired position requires one less arrow down action, because we already start at item 1*/
  
  /*scroll down to the desired location on the list (add .. extra down actions because the menu might have an offset*/  
  for(lp=mem+0; lp>0; lp--)
  {
    Keyboard.press(KEY_DOWN_ARROW);
    Keyboard.releaseAll();
    delay(100);      
  }

  Keyboard.press(KEY_RETURN); /*finalize the selection by opening the selected link*/
  Keyboard.releaseAll();
  delay(100);       

  /*unfortunately, the bookmarks screen is still open, which will cause problems later on, so we must close it now*/
  Keyboard.press(KEY_LEFT_CTRL);
  Keyboard.press(KEY_LEFT_SHIFT);
  Keyboard.press('b');
  Keyboard.releaseAll();
  delay(100);    
  
  Keyboard.press(KEY_LEFT_ALT);     /*the close command*/
  Keyboard.press(KEY_F4);    
  Keyboard.releaseAll();
  delay(100);  
}

void Sound_DialUpModem(void)
{
  unsigned int lp;
  
  Sound_Tone(400, 1500);
  delay(250);
  for(lp=1250;lp>0;lp--)
  { 
    Sound_Tone((200 * random(1, 4)), 8);
  }   
}
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
